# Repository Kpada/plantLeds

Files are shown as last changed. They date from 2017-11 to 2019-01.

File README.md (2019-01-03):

# 4 channel BLE time delay relay

My mom's hobby is growing plants. The device is designed for growing plants in winter and spring, when there is little sunlight in Moscow. 

This is a 4-channel BLE time delay relay based on the Nordic nRF51.
The device has 4 channels. Each channel controls its own group of specific red and blue LEDs. 

IDE: Keil uVision

Many thanks to @sadolit for the android app.

## Hardware

The PCB is designed for DIY.

 - MCU board: Core51822 (nRF51822)
 - AC/DC: ZETTLER ZP01S
 - Triac Driver Output Optocoupler: MOC304

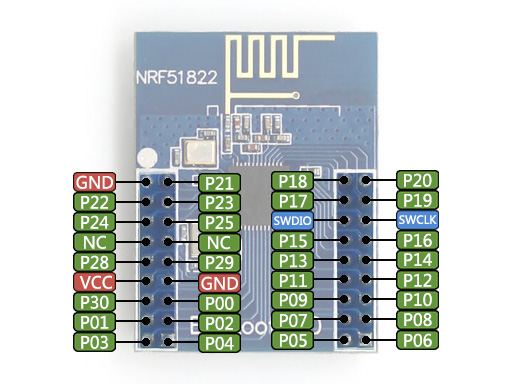
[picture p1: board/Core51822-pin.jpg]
MCU


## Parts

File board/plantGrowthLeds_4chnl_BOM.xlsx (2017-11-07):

Designator | value | package | Quantity
C1, C2, C3, C4 | 0.01u | 1206 | 4
C5 | 47.0uF | B-Size | 1
C6 | 1.0uF | 0805 | 1
DA1 | ZP01SXX00W |  | 1
DD1, DD2, DD3, DD4 | MOC3041 | DIP-6 | 4
FU1 | 250V2A |  | 1
R1, R5, R9, R13 | 330 | 0805 | 4
R2, R6, R10, R14 | 360 | 1206 | 4
R3, R7, R11, R15 | 39 | 1206 | 4
R4, R8, R12, R16 | 330 | 1206 | 4
R17 | 1M | 0805 | 1
U1 | CoreNRF51822 |  | 1
VD1, VD2, VD3, VD4 | BT139 | TO-220AB | 4
XP1, XP2, XP3, XP4, XP5 | DT126-2 | Screw terminal 2 way 5mm | 5

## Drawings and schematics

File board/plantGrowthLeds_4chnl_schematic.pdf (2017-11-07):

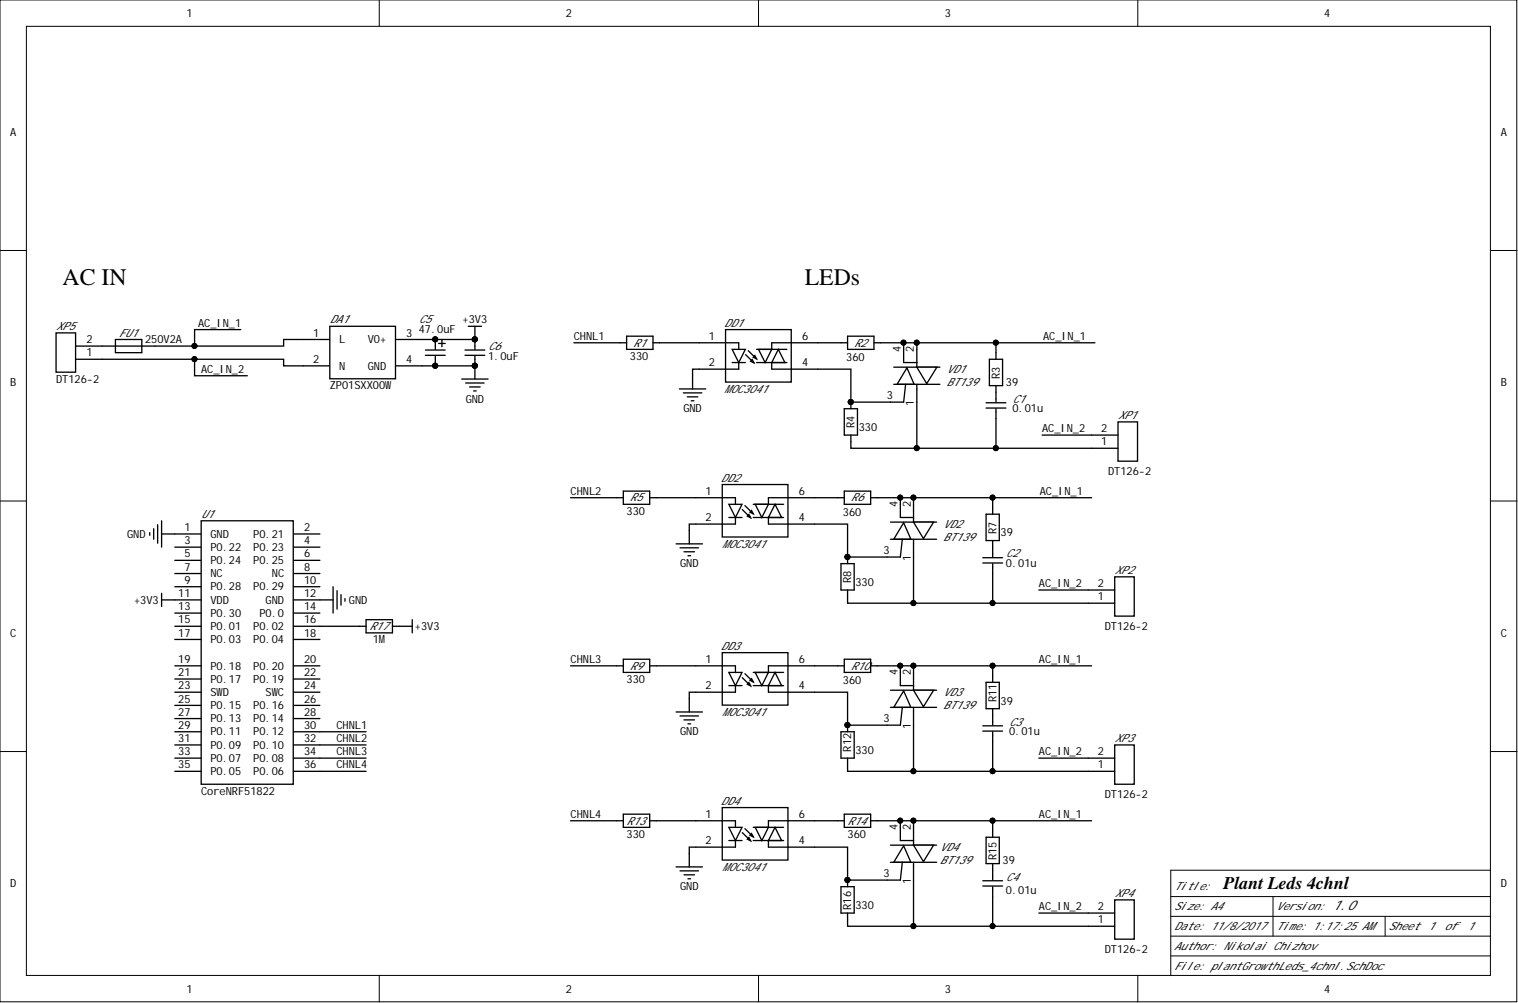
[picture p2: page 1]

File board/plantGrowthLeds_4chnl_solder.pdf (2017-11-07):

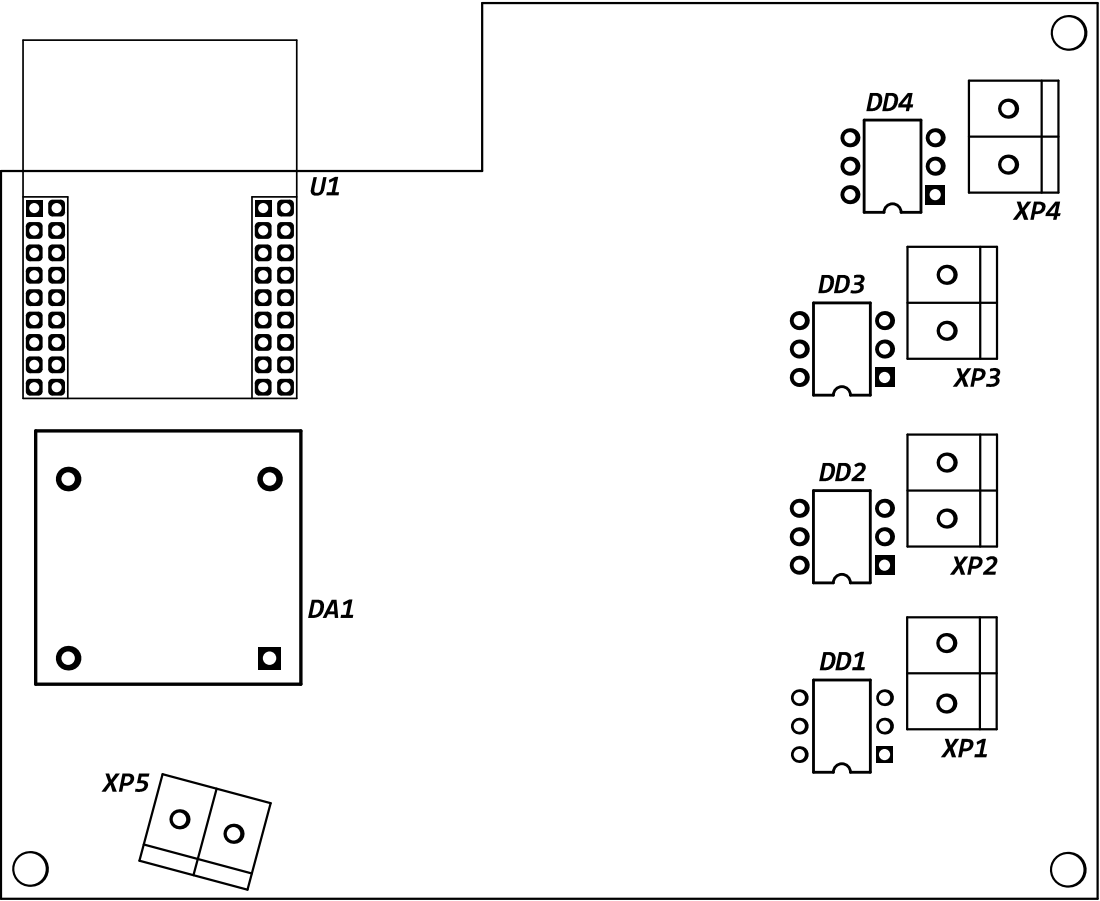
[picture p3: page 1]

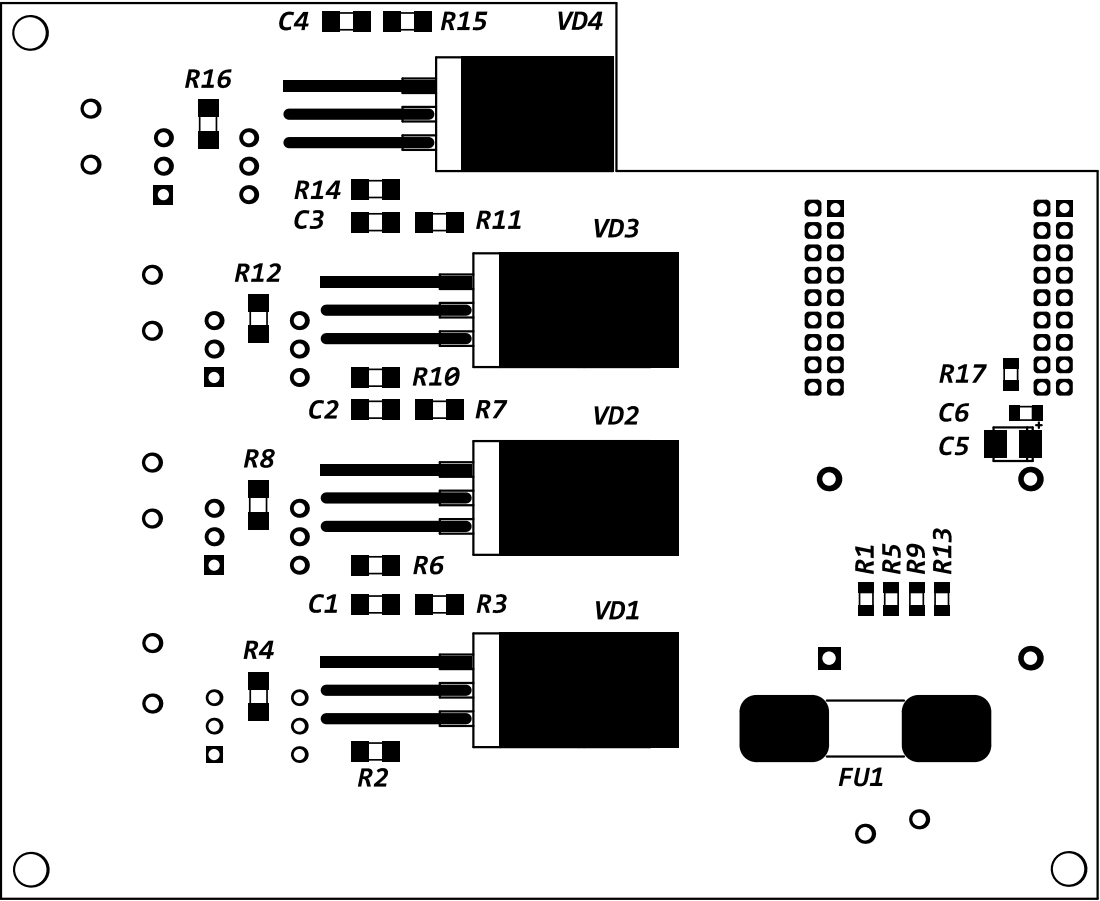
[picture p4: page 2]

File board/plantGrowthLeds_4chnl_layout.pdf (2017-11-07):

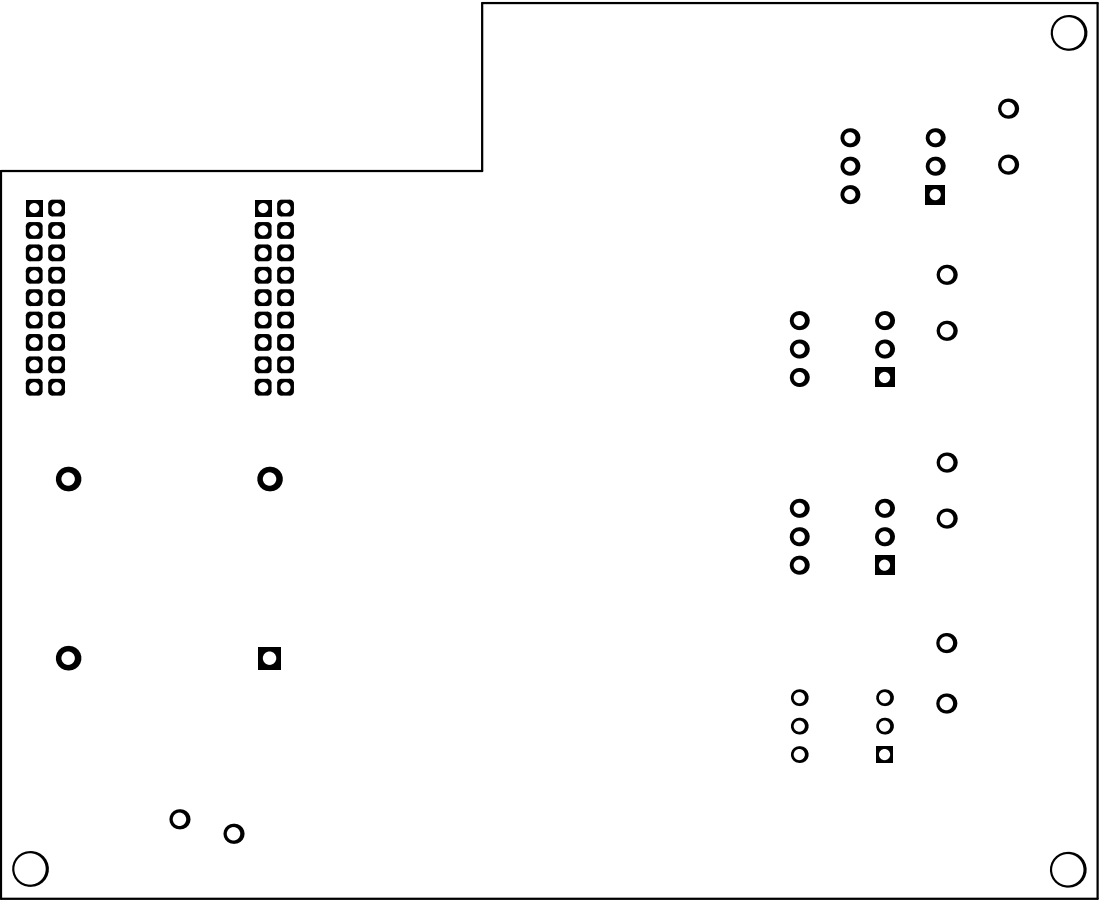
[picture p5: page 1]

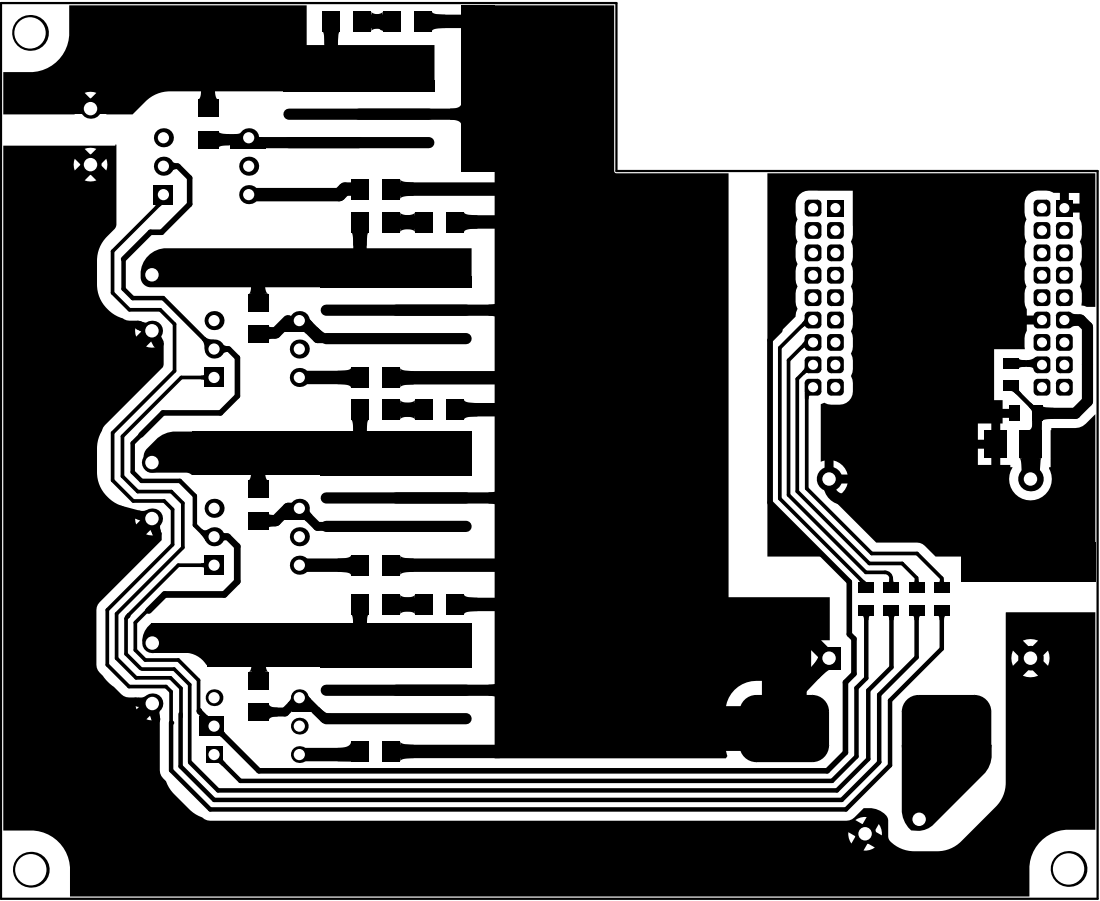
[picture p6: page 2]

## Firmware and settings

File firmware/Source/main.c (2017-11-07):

#include "stdAfx.h"
#include "main.h"

#include "ble/bleServices.h"


/* 
 *      Plant Leds Project for NRF51. 
 *
 *      Softdevice version: s130_nrf51_2.0.0-7.alpha
 *      Please mnote that I used the RTE.
 *
 *
 *      This is a BLE Time Delay Relay for 4 independed channels. 
 *  
 *
 *      Many thanks to Chizhov Alexander for his help with the Android app.
 *
 *
 *      Chizhov Nikolai
 *      2016
 */


// timers
#define APP_TIMER_PRESCALER             0              
#define APP_TIMER_OP_QUEUE_SIZE         4 
//--------------------------------------------------------------------------------------


// application state
appStateType                            g_appState;
//--------------------------------------------------------------------------------------

// wdt
static nrf_drv_wdt_channel_id           s_wdt;
//--------------------------------------------------------------------------------------

// wait for the password
APP_TIMER_DEF( tmrPassword );
#define TMR_PASSWORD_INTERVAL           APP_TIMER_TICKS(APP_WAIT_4_PASSWORD_MS, APP_TIMER_PRESCALER)
//--------------------------------------------------------------------------------------

// rtc
APP_TIMER_DEF( tmrAppTime );
#define TMR_APP_TIME_INTERVAL           APP_TIMER_TICKS(1000, APP_TIMER_PRESCALER)
//--------------------------------------------------------------------------------------


/// application state initialization
///
static void appStateInit (void)
{
    memset( &g_appState, 0, sizeof(g_appState) );       
    g_appState.m_comm.m_hBleConn = BLE_CONN_HANDLE_INVALID;    
}
//--------------------------------------------------------------------------------------

/// password
///
static bool passwordCheckAndHandle (void)
{
    if( g_appState.m_comm.m_isPasswordCorrect ) {
        // do nothing
    }       
    else {
        // disconnect
        if( g_appState.m_comm.m_isConnected ) {
            uint32_t err_code = sd_ble_gap_disconnect(g_appState.m_comm.m_hBleConn, BLE_HCI_REMOTE_USER_TERMINATED_CONNECTION);
            APP_ERROR_CHECK(err_code);
        }
        TRACE_MSG("password incorrect\n");
    }    
    
    return g_appState.m_comm.m_isPasswordCorrect;
}
//--------------------------------------------------------------------------------------

/// password handler
///
void appIsObtainedPasswordCorrect (bool isCorrect)
{
    g_appState.m_comm.m_isPasswordCorrect = isCorrect;
    passwordCheckAndHandle();
}
//--------------------------------------------------------------------------------------

/// make an event
///
void tmrHandlerPw (void * p_context)
{
    UNUSED_PARAMETER(p_context);  
    
    passwordCheckAndHandle();
    TRACE_MSG("timer has been stopped\n");
}
//--------------------------------------------------------------------------------------

/// make an event
///
void tmrHandlerAppTime (void * p_context)
{
    UNUSED_PARAMETER(p_context);
    
    g_appState.m_appTime = g_appState.m_appTime < TIME_T_MAX ? g_appState.m_appTime + 1 : 0;       
    TRACE_MSG("time = %d\n", g_appState.m_appTime);
}
//--------------------------------------------------------------------------------------

/// start the timer
///
static void passwordTimerStart (void)
{
#if defined(USE_PASSWORD_PROTECTION) && 1 == USE_PASSWORD_PROTECTION
    
    TRACE_MSG("password timer has been started\n");
    
    // stop the timer (just in case)
    app_timer_stop(tmrPassword);
    
    // and start it
    uint32_t errCode = app_timer_start(tmrPassword, TMR_PASSWORD_INTERVAL, NULL);
    APP_ERROR_CHECK(errCode); 
    
#endif     
}
//--------------------------------------------------------------------------------------

/// Initialize timer module, making it use the scheduler
///
static void appTimersInit (void)
{
    APP_TIMER_INIT( APP_TIMER_PRESCALER, APP_TIMER_OP_QUEUE_SIZE, false ); 
    
    uint32_t errCode;
       
    // password
    errCode = app_timer_create(
        &tmrPassword,
        APP_TIMER_MODE_SINGLE_SHOT,
        tmrHandlerPw
    );
    APP_ERROR_CHECK(errCode);
    
    // time
    errCode = app_timer_create(
        &tmrAppTime,
        APP_TIMER_MODE_REPEATED,
        tmrHandlerAppTime
    );
    APP_ERROR_CHECK(errCode);
    
    // start
    errCode = app_timer_start(tmrAppTime, TMR_APP_TIME_INTERVAL, NULL);
    APP_ERROR_CHECK(errCode); 
}   
//--------------------------------------------------------------------------------------

/// on BLE event handler
///
void appOnBleEvtHandle (ble_evt_t* evt)
{
    TRACE_MSG("onBleStackEvt: %d\n", evt->header.evt_id );
    
    switch( evt->header.evt_id ) {
        // connected
        case BLE_GAP_EVT_CONNECTED:
            TRACE_MSG("Connected\n\n");
            g_appState.m_comm.m_hBleConn = evt->evt.gap_evt.conn_handle;
            g_appState.m_comm.m_isConnected = true;                 
            passwordTimerStart();
            break;
        
        // disconnected
        case BLE_GAP_EVT_DISCONNECTED:
            TRACE_MSG("Disconnected\n\n");
            g_appState.m_comm.m_hBleConn = BLE_CONN_HANDLE_INVALID;
            g_appState.m_comm.m_isConnected = false;
            g_appState.m_comm.m_isPasswordCorrect = false;
            bleAdvertisingStart();
            break;
        
        // default
        default:
            break;
    }
}
//--------------------------------------------------------------------------------------

/// watchdog init
///
static void wdtInit (void)
{
    // init
    nrf_drv_wdt_config_t config = { 
        .behaviour          = NRF_WDT_BEHAVIOUR_RUN_SLEEP,    
        .reload_value       = APP_WDT_RELOAD_VALUE_MS, 
        .interrupt_priority = APP_IRQ_PRIORITY_HIGH, 
    };
    
    uint32_t err_code = nrf_drv_wdt_init(&config, NULL);
    APP_ERROR_CHECK(err_code);
    
    // alloc
    err_code = nrf_drv_wdt_channel_alloc(&s_wdt);
    APP_ERROR_CHECK(err_code);
    
    // start
    nrf_drv_wdt_enable();
}
//--------------------------------------------------------------------------------------

/// check adn apply new time
///
void appNewTimeObtained (time_t time)
{
    // check the password 
    if( passwordCheckAndHandle() ) {
        // check the borders
        if( time < TIME_T_MAX )
            g_appState.m_appTime = time;
    }
}
//--------------------------------------------------------------------------------------

/// check and apply a new state
///
void appNewLedStateObtained (led_t* led, uint32_t ledIdx)
{    
    // check
    if( passwordCheckAndHandle() && ledsValueCheck(led, ledIdx) && ledIdx < LEDS_NUMBER ) {
        // apply
        g_appState.m_leds[ledIdx] = *led;
        //
        TRACE_MSG("led %d has been updated: on = %d, off = %d\n", ledIdx, led->time.timeTurnOn, led->time.timeTurnOff);
    }
}
//--------------------------------------------------------------------------------------

/// main
///
int main (void)
{     
    // wdt
    wdtInit();
    
    // application state
    appStateInit();
    
    // trace
    TRACE_INIT();
    
    // timer
    appTimersInit(); 
    
    // ble stack
    bleStackInit();
    // ble services
    bleServicesInit();
    // start 
    bleAdvertisingStart();
    
    // init
    ledsInit(g_appState.m_leds);
        
    // while
    for ever {
        // wait for an event
        sd_app_evt_wait();
        
        // feed a wdt
        nrf_drv_wdt_channel_feed(s_wdt);
             
        // leds
        ledsRoutine(g_appState.m_leds, g_appState.m_appTime);
        
        // time & leds
        if( g_appState.m_comm.m_isConnected ) {
            // time
            ble_svc_pw_tm_time_update(&g_appState.m_comm.m_ble_svc_pw_tm, g_appState.m_appTime);
            // leds
            ble_svc_leds_update(&g_appState.m_comm.m_ble_svc_leds, g_appState.m_leds);
        }
    }        
}
//--------------------------------------------------------------------------------------

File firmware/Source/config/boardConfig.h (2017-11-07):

#ifndef __APP_CONFIG_H__
#define __APP_CONFIG_H__

// app version string
#define APP_VERSION_STR                 "1.2"           // software version string
// app name string
#define APP_NAME_STR                    "plantLeds"     // software name string
//--------------------------------------------------------------------------------------

// config 
#define USE_PASSWORD_PROTECTION         1               // you can disable this timer (if you gonna test the target)
//--------------------------------------------------------------------------------------

// number of leds
#define LEDS_NUMBER                     4               // number of leds
//--------------------------------------------------------------------------------------

#if 4 == LEDS_NUMBER
    // gpio
    typedef enum {
        led0    = 8,    
        led1    = 10,   
        led2    = 6,
        led3    = 12,
    } led_list; 
#endif
//--------------------------------------------------------------------------------------

// adc pin
#define PIN_ADC_PWR                     NRF_ADC_CONFIG_INPUT_3  // P0.02, the feature is now available
//--------------------------------------------------------------------------------------

// timers
#define APP_WDT_RELOAD_VALUE_MS         8000                    // watchdog timeout, msec
#define APP_WAIT_4_PASSWORD_MS          10000                   // password timeout, msec
//--------------------------------------------------------------------------------------

// specific
#define DEVICE_NAME                     "Leds"                  // advertizing name
//--------------------------------------------------------------------------------------
    
// low freq source external/internal rc
// PS: Don't judge me. I was using 2 different boards for debug and release
#ifdef DEBUG
    #define CLOCK_LFCL_SRC              NRF_CLOCK_LFCLKSRC_RC_250_PPM_1000MS_CALIBRATION    // an internal RC
#else
    #define CLOCK_LFCL_SRC              NRF_CLOCK_LFCLKSRC_XTAL_20_PPM                      // an external crystal
#endif
//--------------------------------------------------------------------------------------

// advertising period
#define BLE_ADVERTISING_PERIOD_MSEC     500                 // advertising period, msec
// connection intervals
// attention. be careful cuz slow device won't wokrs well
#define BLE_CONN_INTRVL_MIN_MSEC        100                 // min connevtion period, msec
#define BLE_CONN_INTRVL_MAX_MSEC        200                 // max connection period, msec
//--------------------------------------------------------------------------------------

// tx gain level
#define BLE_TX_GAIN_dB                  4                   // see sd_ble_gap_tx_power_set
//--------------------------------------------------------------------------------------


/// UIDs
///

// base
#define SVC_UUID_BASE                   {   0x01, 0x00, 0x00, 0x00, 0x00, 0x00, 0x00, 0x00, \
                                            0x00, 0x00, 0x00, 0x00, 0x00, 0x00, 0x00, 0x00  }
//--------------------------------------------------------------------------------------

// password and time
#define SVC_PW_UUID_SERVICE             ( 0x1000 )                      // base
#define SVC_PW_UUID_CHAR                ( SVC_PW_UUID_SERVICE  + 1 )    // password set
#define SVC_TIME_UUID_CHAR              ( SVC_PW_UUID_CHAR     + 1 )    // time set & get
//--------------------------------------------------------------------------------------

// leds                                    
#define SVC_LEDS_UUID_SERVICE           ( 0x2000 )                      // base
#define SVC_LEDS_UIID_CHAR_BASE         ( SVC_LEDS_UUID_SERVICE + 1 )   // the first uuid value
//--------------------------------------------------------------------------------------
  
                                 
#endif // __APP_CONFIG_H__
